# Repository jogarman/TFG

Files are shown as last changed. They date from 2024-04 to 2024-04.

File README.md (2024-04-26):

## Proyecto Fin de Grado de Ingeniería Mecánica
### Presentado en septiembre de 2016 en la Universidad de Salamanca



Echale un vistazo al ->
[Resumen.pdf](https://github.com/jogarman/TFG/files/15133371/Resumen.pdf)

Los videos, esquemas y código también son interesantes!!

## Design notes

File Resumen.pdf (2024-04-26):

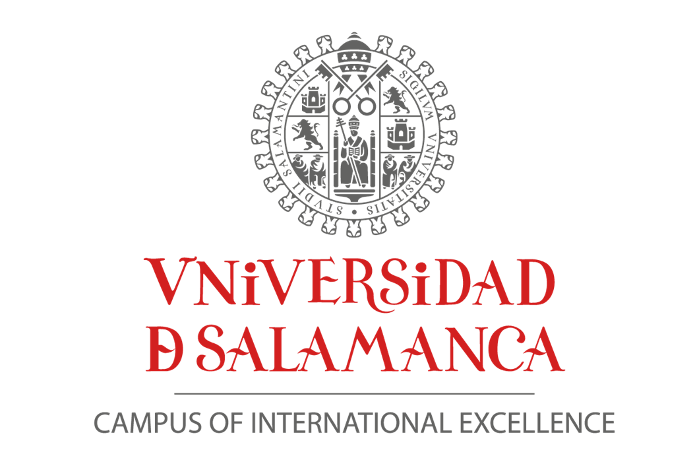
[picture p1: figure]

## DISEÑO Y REALIZACIÓN DE UN ROBOT BÍPEDO MICROCONTROLADO

GRADO EN INGENIERÍA MECÁNICA ESCUELA POLITÉCNICA SUPERIOR DE ZAMORA DEPARTAMENTO DE FÍSICA APLICADA ÁREA DE ELECTRÓNICA

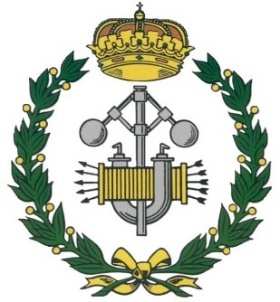
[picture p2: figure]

TFG-RESUMEN

AUTOR: JOSÉ GARCÍA MANZANARO

TUTOR: BEATRIZ GARCÍA VASALLO

COTUTOR: MIGUEL ÁNGEL RABANILLO DE LA FUENTE

FECHA DE ADJUDICACIÓN: MARZO DE 2016

FECHA DE PRESENTACIÓN: SEPTIEMBRE DE 2016

TFG-Resumen | José García Manzanaro
1 | P á g i n a

RESUMEN

El presente proyecto explica el funcionamiento y fabricación de un robot bípedo autónomo. Dicho robot es capaz de caminar frontalmente, girar a los lados y detectar obstáculos siempre asistido por un acelerómetro con giróscopo y un sensor de ultrasonidos.

Es un trabajo que ha sido multidisciplinar desde el primer momento. Combina varias técnicas: diseño mecánico, impresión 3D, electrónica y programación que unidas dan lugar a la mecatrónica orientada a la bipedestación.

Comienza con una introducción sobre el estado de la técnica en robótica y en la impresión 3D por deposición. En este punto, hay recalcar que se construyó una impresora 3D para la realización del robot.

A continuación, el trabajo se desglosa en 4 capítulos:

- Capítulo 1. Mecánica del robot
- Capítulo 2. Electrónica
- Capítulo 3. Programación y código
- Capítulo 4. Bipedestación y características finales.

CAPÍTULO 1. MECÁNICA DEL ROBOT

En esta sección se explica cómo fue diseñado y construido en orden cronológico

- Diseño global
- Diseño de los engranajes para las articulaciones
- Diversas uniones
- Ilustración con diseño final

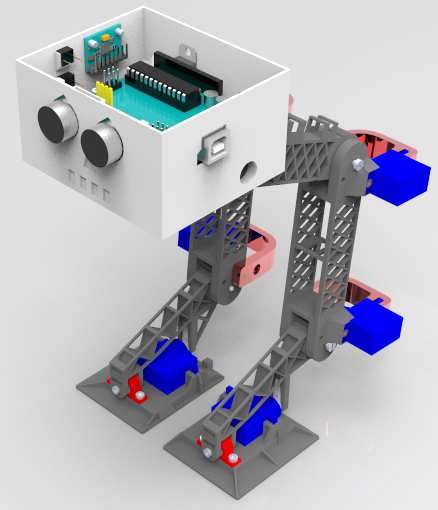
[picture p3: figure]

Ilustración 1. Diseño final

CAPÍTULO 2. ELECTRÓNICA

Se enumeran todos los componentes y se explica el funcionamiento de todos ellos, haciendo especial hincapié en el acelerómetro con giróscopo, también llamado IMU (Inertial Motion Unit) o MPU (Motion Process Unit). Entre estos dos términos existe una diferencia que se explica en la introducción de este punto. El esquema del apartado IMU es el siguiente:

- Protocolo I2C
- Tecnología MEMS (MicroElectroMechanical Systems)
- Funcionamiento del acelerómetro
- Funcionamiento del giróscopo
- Filtro complementario

CAPÍTULO 3. PROGRAMACIÓN Y CÓDIGO

En este capítulo se explica el funcionamiento de las rutinas principales haciendo referencia al código y organigramas de los anexos. También se describe el funcionamiento de la forma de caminar y cómo interactúa con el acelerómetrogiróscopo y cómo detecta obstáculos y gira, pero rutina a rutina.

Las rutinas explicadas son:

- IrA. Convierte el valor de la articulación al valor que recibe el servo.
- Posición de Inicio. Equilibra la cabeza colocándola en horizontal. Funciona sobre planos inclinados
- Ir Hasta. Se inclina lateralmente
- Zancada derecha/izquierda. Da una zancada
- Ir A Paso. Lleva al robot una posición (o a un paso) determinada, en un tiempo determinado y detecta si se cae
- Evitar desde derecha/izquierda. Detecta y evita obstáculos
- Programa Caminar1. Programa principal. Camina recto, detecta obstáculos y gira con ayuda del acelerómetro y giróscopo. Es lento
- Programa Caminar2. Programa secundario. Más primitivo. Solo camina, pero es más rápido

En los anexos pueden encontrarse el código y los organigramas de estas rutinas y algunos más.

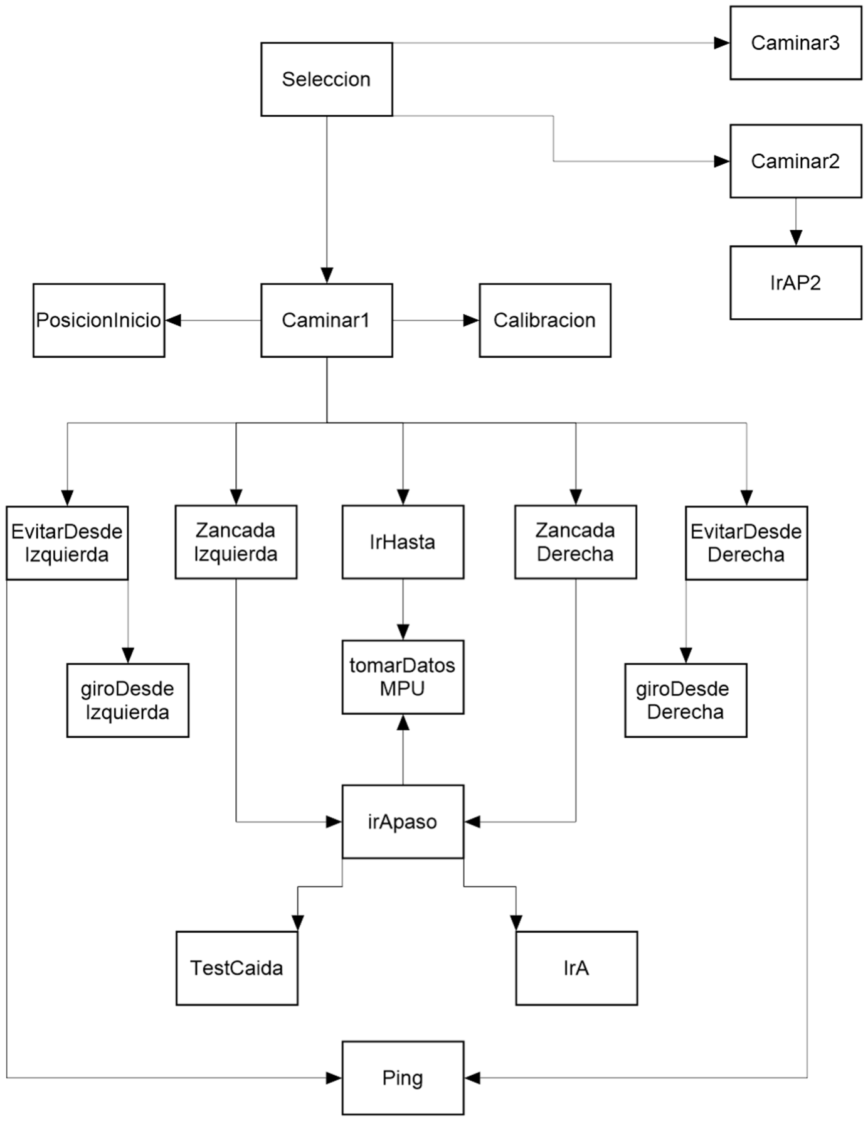
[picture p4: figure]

Ilustración 2. Organigrama del código

CAPÍTULO 4. BIPEDESTACIÓN Y CARACTERÍSTICAS FINALES

En la parte de la bipedestación se explica cómo funciona el robot:

El avance del robot es simple: se inclina, se levanta una pierna, se la hace avanzar, se asienta en una nueva posición y se inclina hacia la nueva posición. Al final de cada zancada utiliza el sensor de ultrasonidos para saber si hay algún obstáculo, y si lo hay, lo rodea en la dirección opuesta a la zancada (si es la zancada izquierda, lo rodea hacia la derecha, y viceversa).

Durante la elaboración de los códigos de movimiento se encontraron algunas reglas y particularidades a las que se hace referencia:

- Sumatorio de ángulos igual a 360

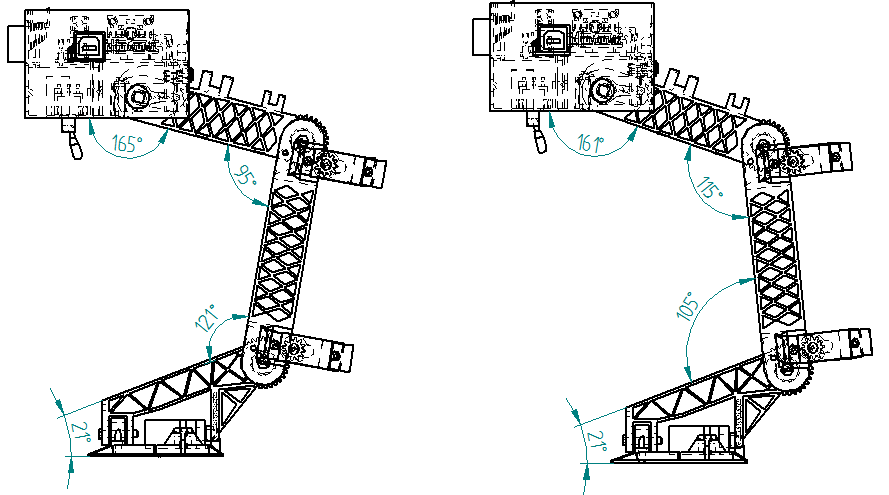
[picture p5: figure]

Para asentar el pie, se comprobó que los ángulos debían sumar lo mismo. En la teoría 360º

- Enlace entre zancadas

Se explica cómo se consiguió que caminara recto renunciando a caminar rápido. Consiste en cambian la distribución de pesos lateralmente y no en diagonal. Cuando se hace en diagonal el pie nunca se apoya completamente recto, principalmente por la baja precisión de los componentes.

- Caminar recto

Se profundiza en los problemas que tiene el robot para caminar recto y se concluye que la mejor forma para que así lo hiciera sería añadir un magnetómetro para conocer el norte terrestre y poder corregir el rumbo cuando sea necesario

En cuanto a características finales de algunos parámetros importante del proyecto:

- Desglose de coste
- Características técnicas finales
- Líneas de futuro

ANEXOS

En los anexos, aparte de encontrar el código completo explicado y con ordinogramas y demás tablas y datos relativos al proyecto, se encuentra la lista de piezas con los diseños en CAD impresos, y los componentes (también en CAD) modelizados para este proyecto.

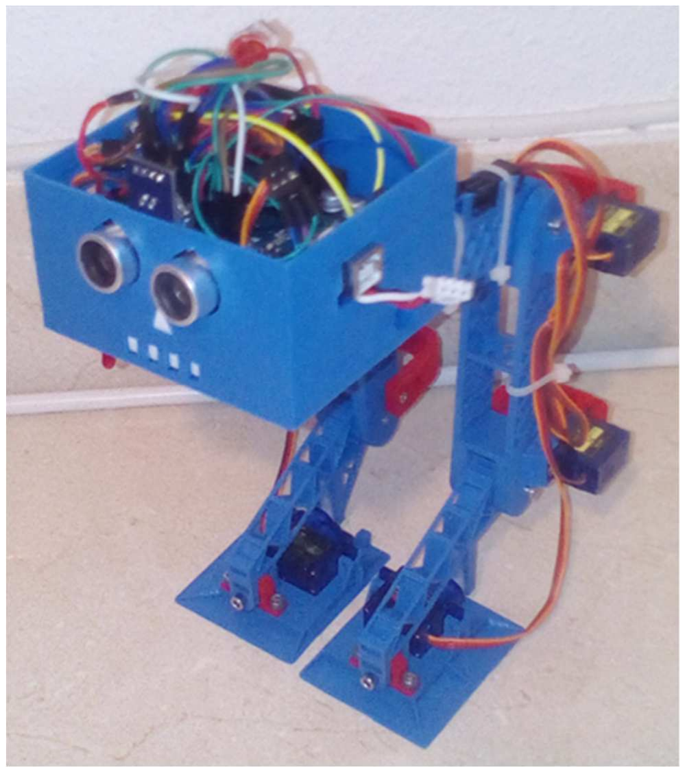
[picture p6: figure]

Ilustración 3. Fotografía final del robot

FUENTES DE INFORMACIÓN

- Esteban Viso El origen de la palabra robot. Enero 2016 http://m.xatakaciencia.com/robotica/el-origen-de-la-palabra-robot
- Real Academia Española
http://dle.rae.es/?id=WYRlhzm
- Escuela técnica Superior de Ingeniería de Sistemas Informáticos. Universidad Politécnica de Madrid https://www.etsisi.upm.es/museo_virtual/origenes/jmjacquard
- Comunicación en visita (2010) y Centro de Automática y Robótica (CAR) CSIC-UPM.
- Honda Motor Co.
http://world.honda.com/ASIMO/technology/2000/index.html
- Distribuidor Oficial de Nao
http://aliverobots.com/nao
- E. Ackerman and E. Guizzo Spectrum Boston Dynamics Now Belongs to Google IEEE 14 Dec 2013
http://spectrum.ieee.org/automaton/robotics/military-robots/bostondynamics-now-belongs-to-google
- E. Ackerman, ATLAS DRC Robot Is 75 Percent New, Completely Unplugged. Spectrum IEEE, 20 junio 2015: http://spectrum.ieee.org/automaton/robotics/military-robots/atlas-drcrobot-is-75-percent-new-completely-unplugged
- Página oficial de Boston Dynamics.
www.bostondynamics.com
- Página oficial del proyecto ICub http://www.icub.org/

- E. Guizzo Researchers Build Fast Running Robot Inspired by Velociraptor Spectrum IEEE. 29 May 2014 http://spectrum.ieee.org/automaton/robotics/robotics-hardware/fastrunning-biped-robot-based-on-velociraptor
- Comunicación en conferencia en la Escuela Politécnica Superior de Zamora. 2014
- Especificaciones de los plásticos. hxx, proovedor de sistemas de impresión 3D
http://hxx.es/2015/03/12/materiales-de-impresion-3d-i-pla-acidopolilactico/
http://hxx.es/2015/03/23/materiales-de-impresion-3d-ii-abs-acrilonitrilobutadieno-estireno/
- Página oficial de Arduino. https://www.arduino.cc/en/Reference/Comparison
- Página oficial de Fritzing http://fritzing.org/projects/mpu-6050-board-gy-521-acelerometro-ygiroscopio
- Página oficial del fabricante (Invensense) del MPU6050 https://www.invensense.com/products/motion-tracking/6-axis/mpu-6050/
- Página especializada en tutoriales de Arduino http://www.prometec.net/bus-i2c/
- Página de los laboratorios SANDIA http://www.sandia.gov/mstc/mems_info/movie_gallery.html
- National Informal STEM Education Network (NISE Network) http://www.nisenet.org/sites/default/files/catalog/uploads/spanish/12194/electricsqueeze_images_13nov13_sp.pdf
- Página oficial del fabricante PCB http://www.pcb.com/techsupport/tech_accel.aspx

- Hoja de especificaciones MPU-6050 https://www.invensense.com/products/motion-tracking/6-axis/mpu-6050/
- Instrumentation-Electronics http://www.instrumentationtoday.com/?s=accelerometer
- Á. Solera Ramírez. El filtro de Kalman. Banco central de costa rica división económica departamento de investigaciones económicas. 2003

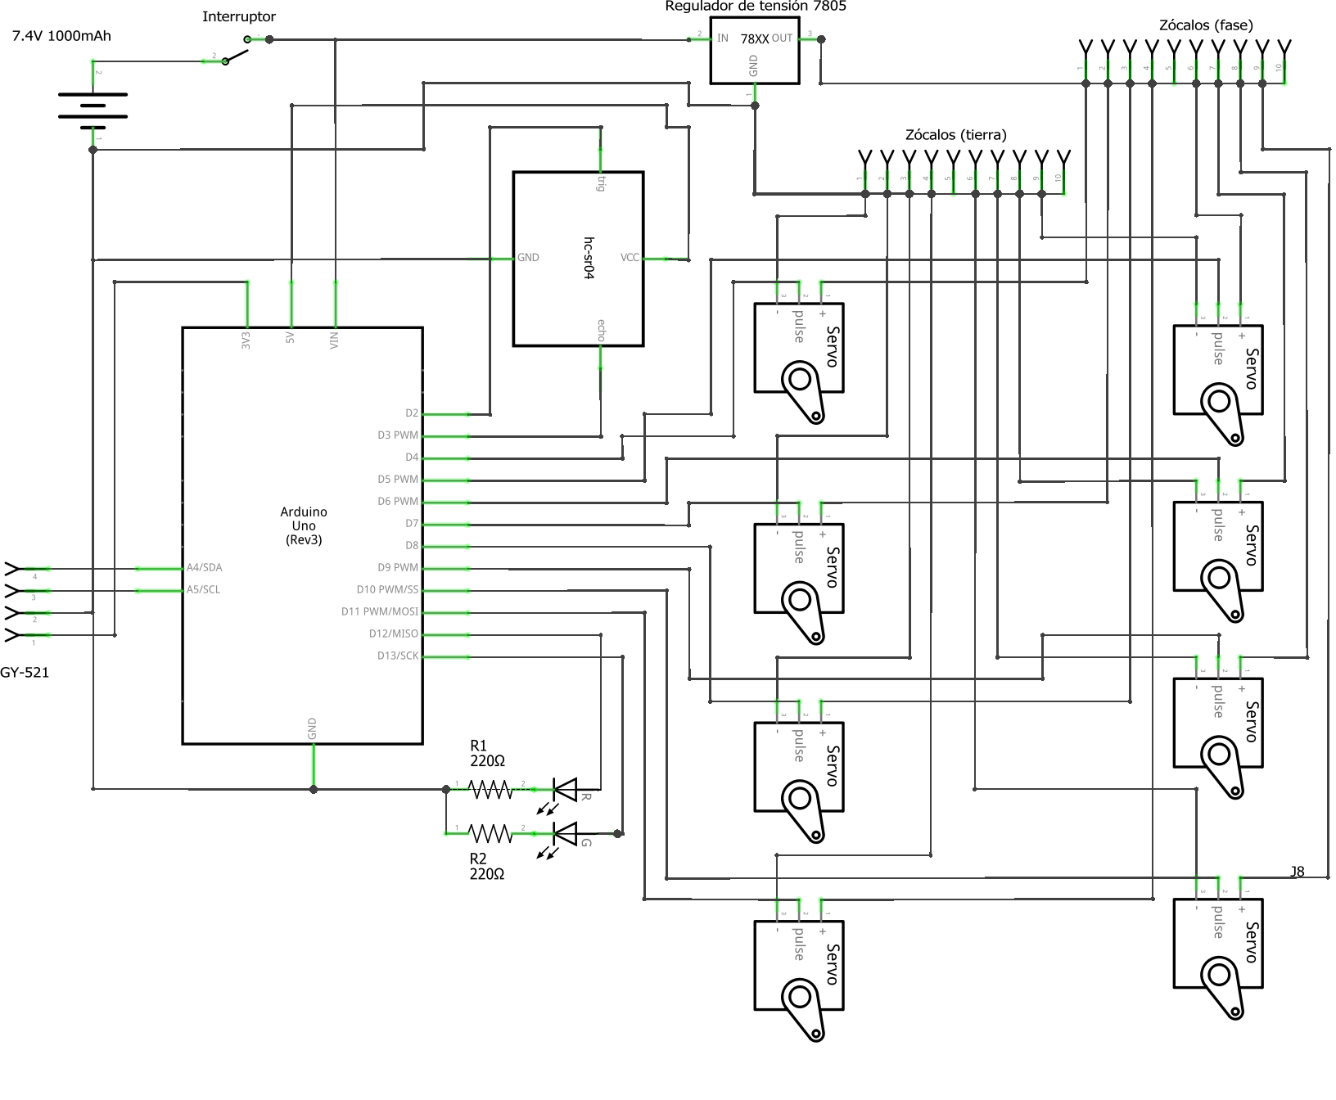
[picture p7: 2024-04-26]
Planos eléctricos/Plano electrico global.png

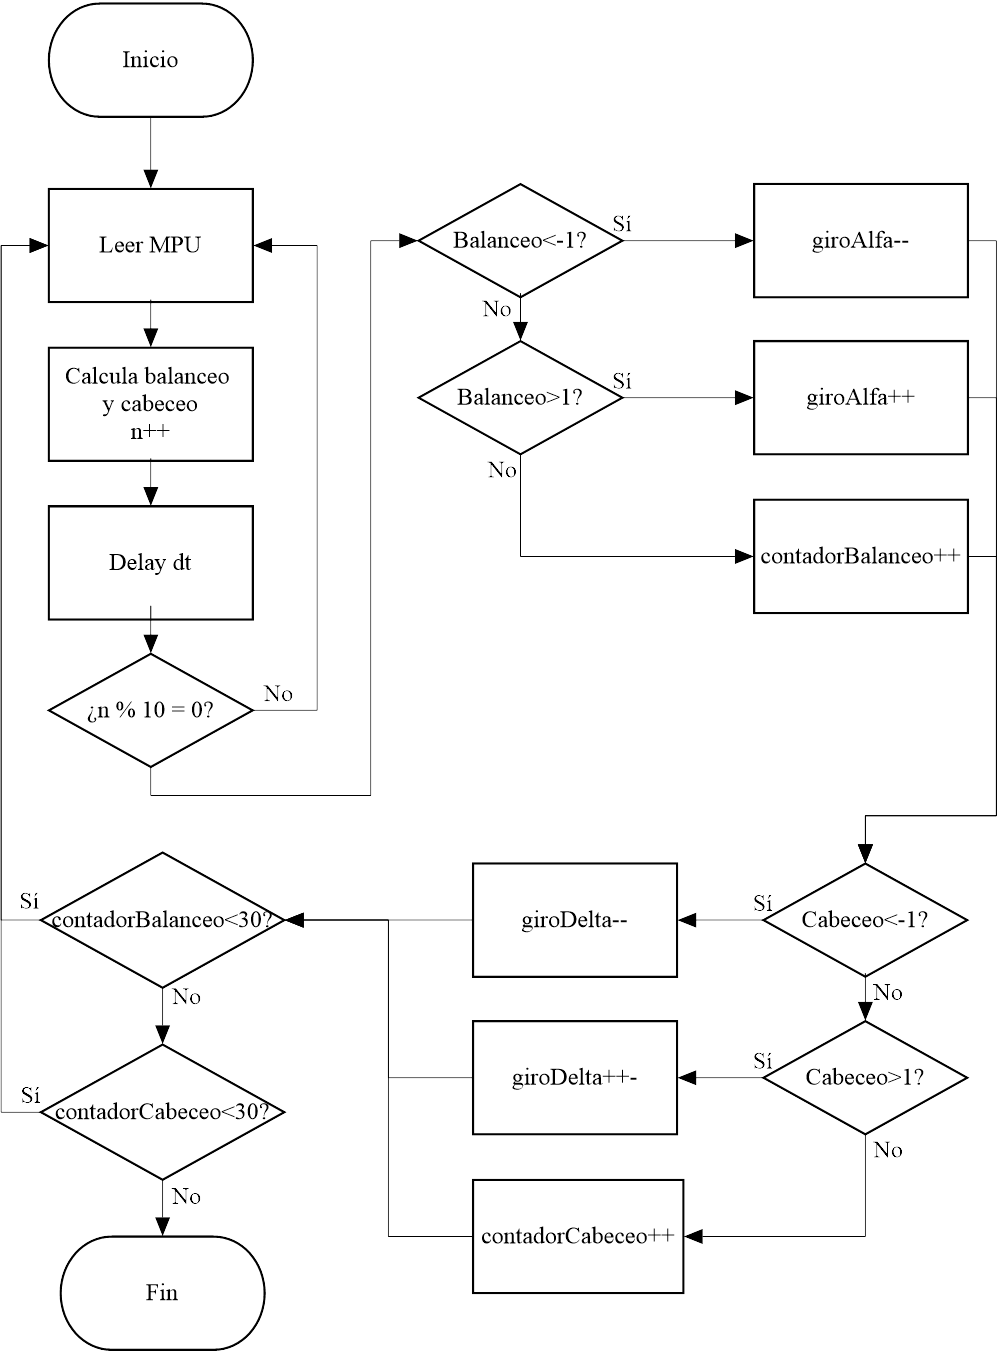
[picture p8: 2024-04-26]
Organigramas/posicionInicio.png

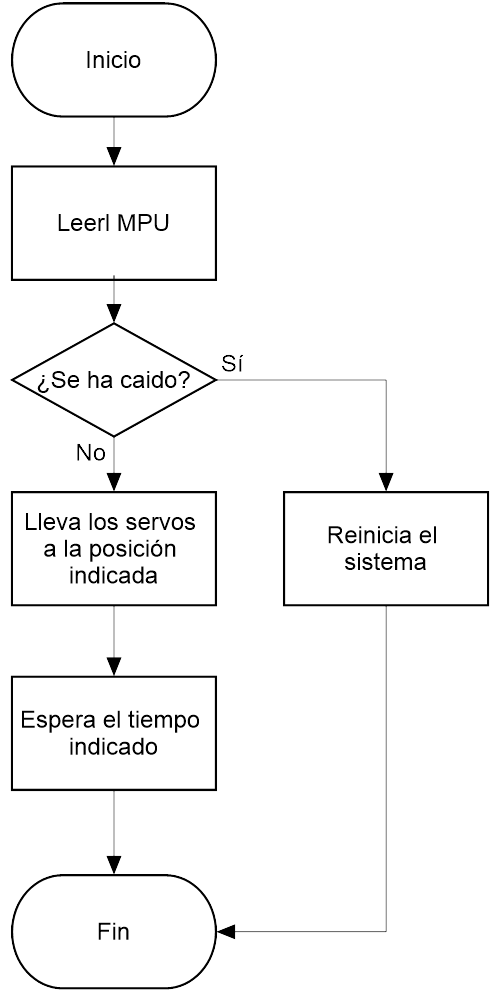
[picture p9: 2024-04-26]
Organigramas/IrAPaso.png

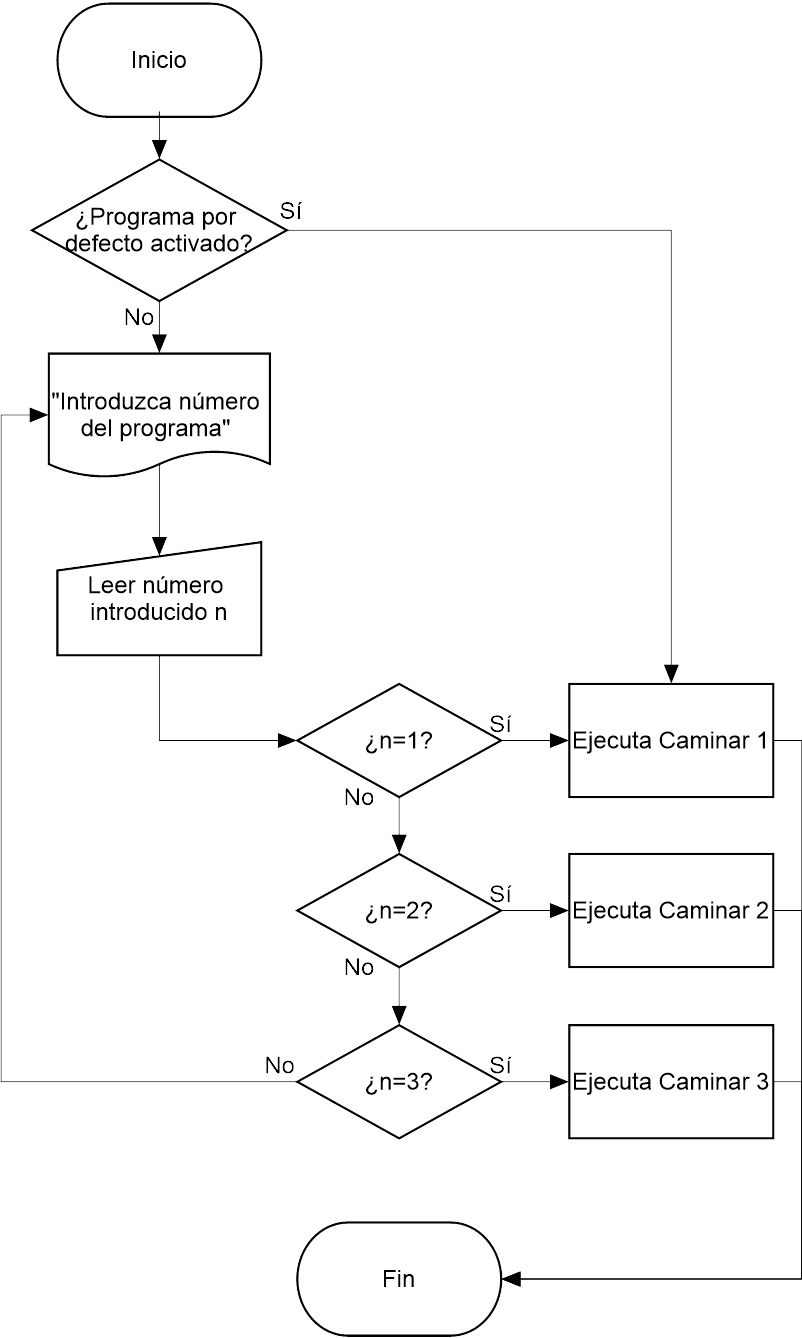
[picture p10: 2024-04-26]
Organigramas/Selector.png

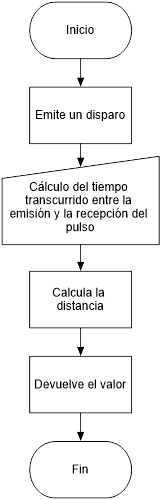
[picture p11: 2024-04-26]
Organigramas/ultrasonidos.png

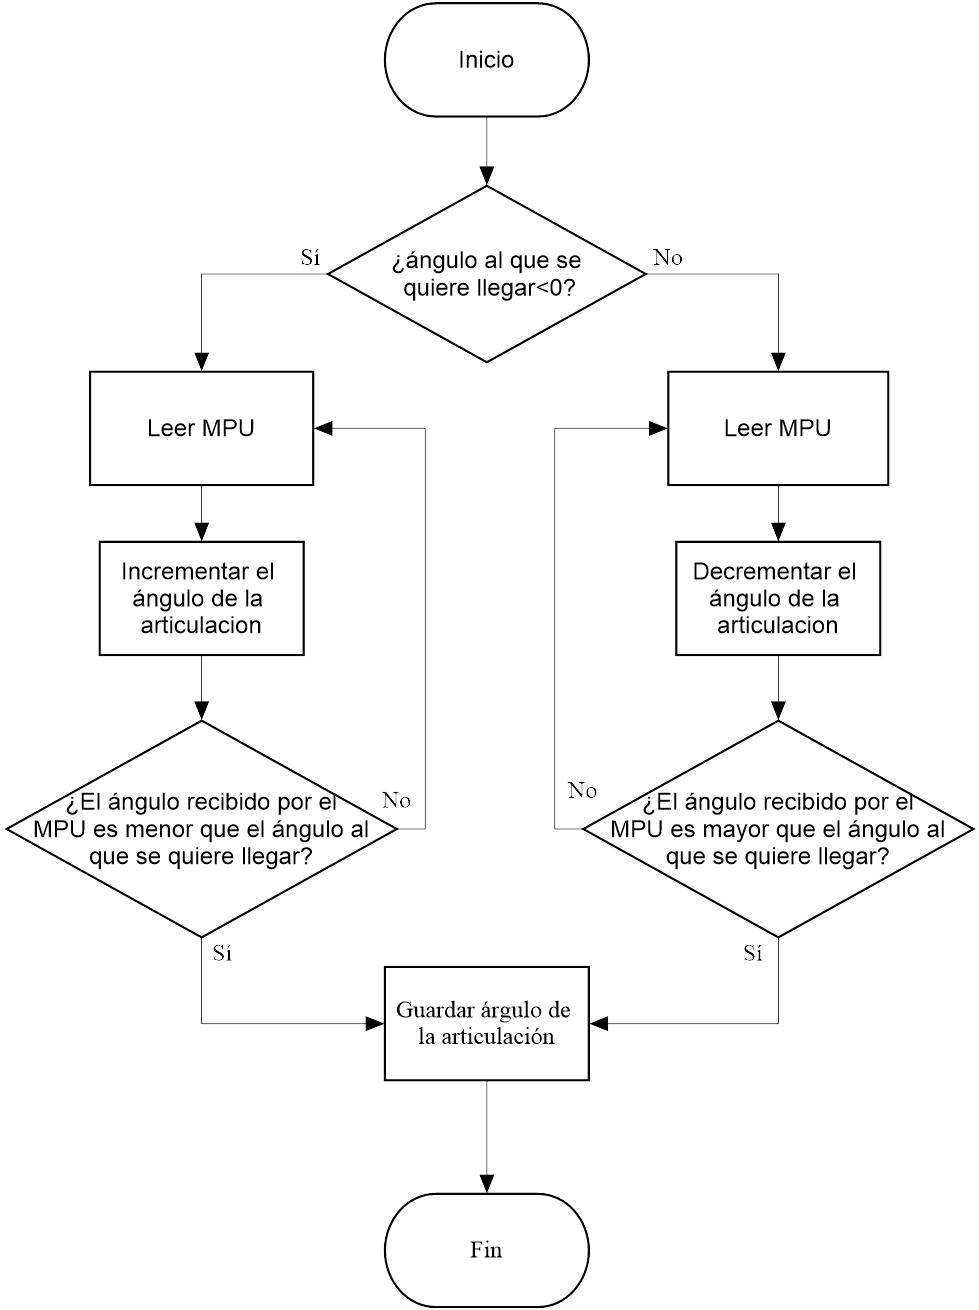
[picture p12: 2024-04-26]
Organigramas/irHasta V2.png

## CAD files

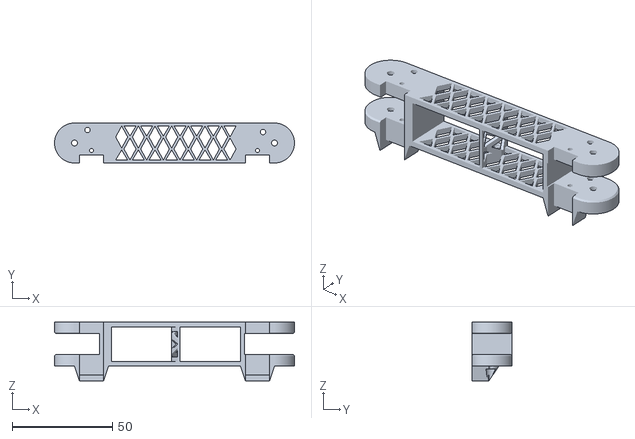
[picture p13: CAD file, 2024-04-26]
Archivos para imprimir 3D .stl/1.05 ESPINILLA n.stl
120.0 x 20.0 x 29.4

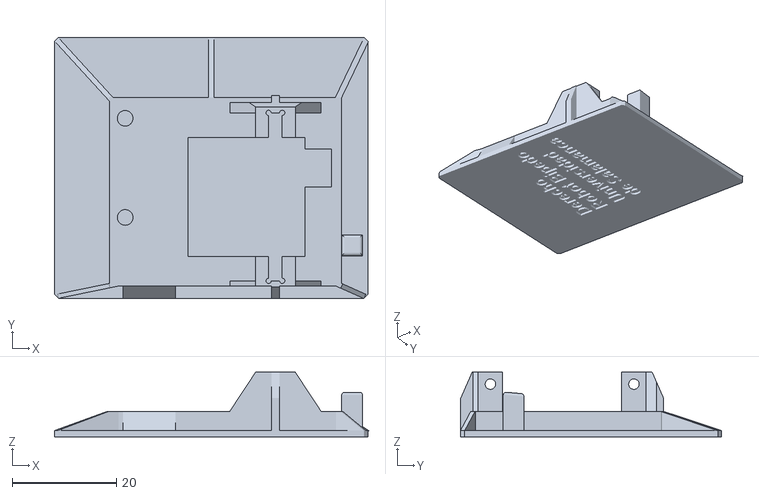
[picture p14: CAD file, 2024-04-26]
Archivos para imprimir 3D .stl/1.01b PIE.stl
60.2 x 50.1 x 12.4

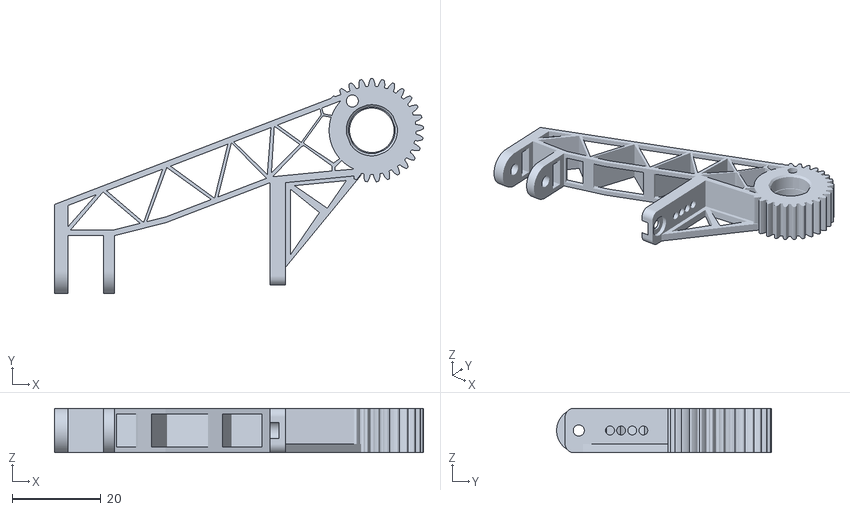
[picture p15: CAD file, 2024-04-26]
Archivos para imprimir 3D .stl/1.04 EMPEINE.stl
83.0 x 48.3 x 10.0

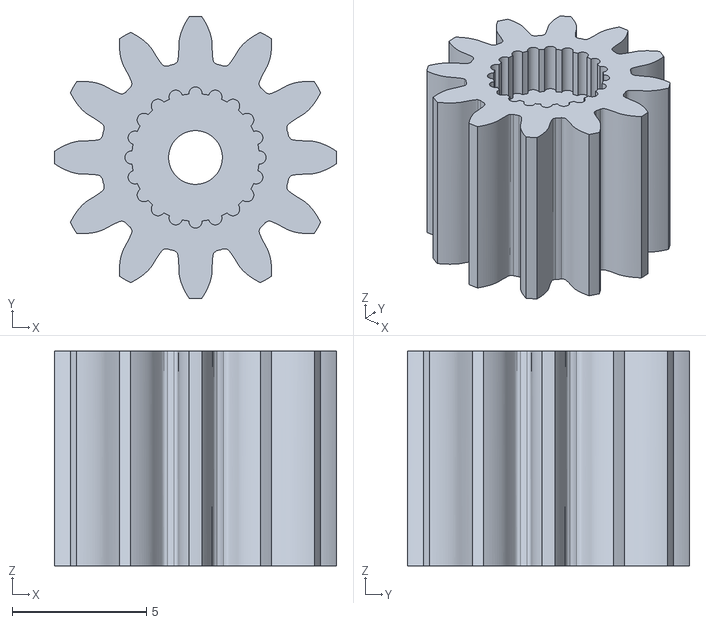
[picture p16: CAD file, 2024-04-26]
Archivos para imprimir 3D .stl/1.03 PIÑON.stl
10.5 x 10.5 x 8.00

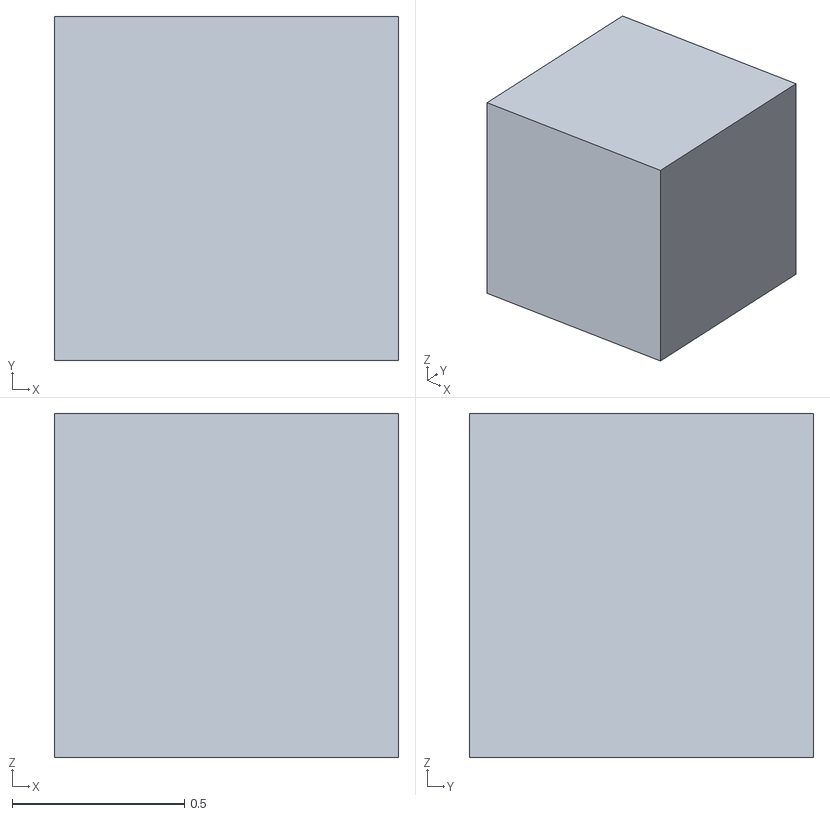
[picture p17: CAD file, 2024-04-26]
Archivos para imprimir 3D .stl/cubo 1x1x1 para extruir piñones.stl
1.00 x 1.00 x 1.00

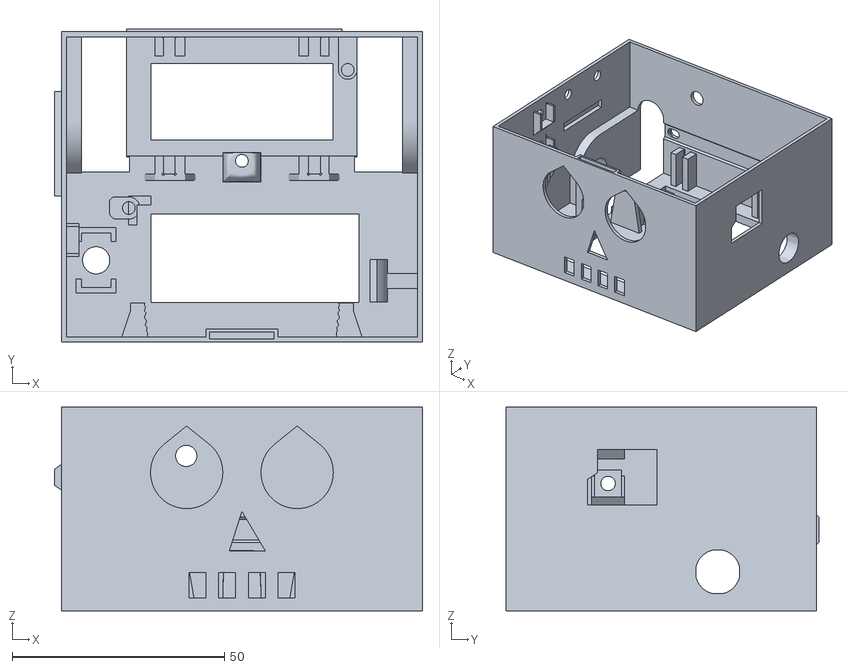
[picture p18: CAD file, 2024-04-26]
Archivos para imprimir 3D .stl/1.07 CAJA CABEZA.stl
86.6 x 73.6 x 48.0

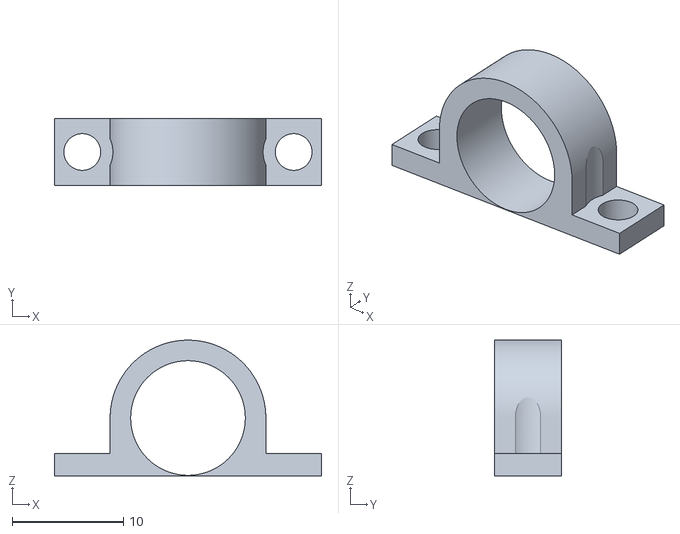
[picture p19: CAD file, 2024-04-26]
Archivos para imprimir 3D .stl/1.02 SOPORTE PIE.stl
24.0 x 6.00 x 12.2

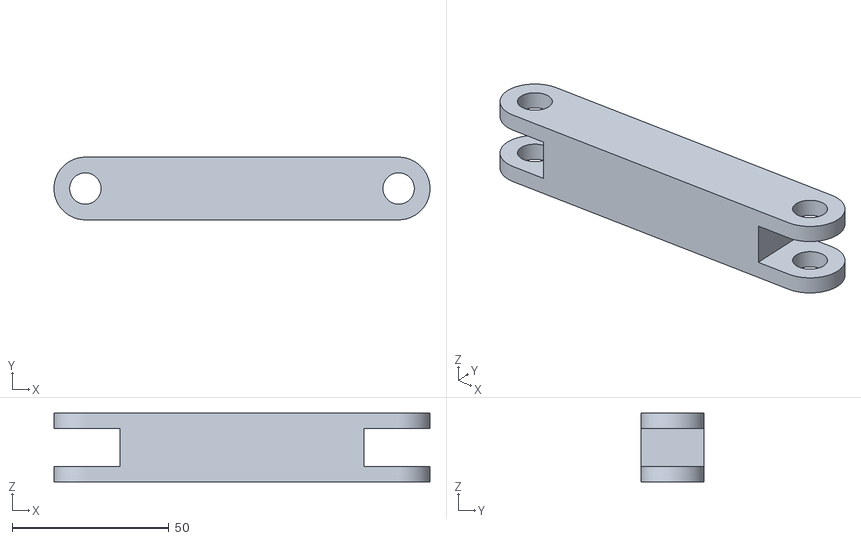
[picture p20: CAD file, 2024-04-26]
Archivos para imprimir 3D .stl/1.05 espinilla.stl
120.0 x 20.0 x 22.0

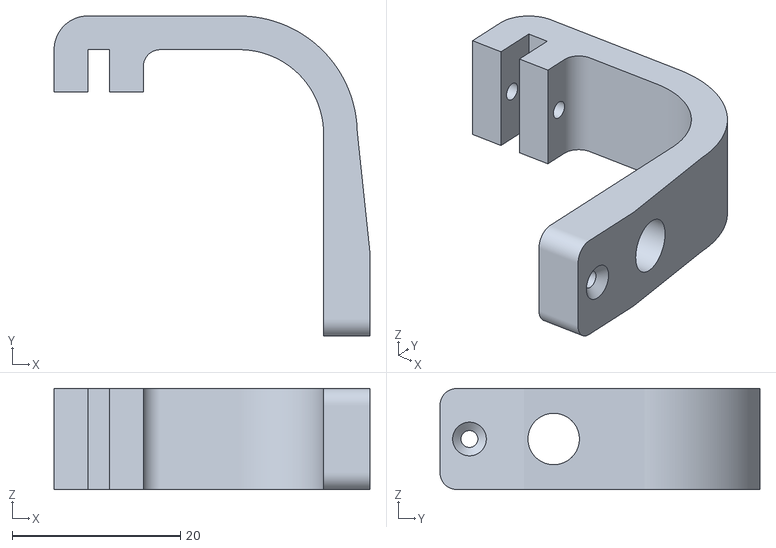
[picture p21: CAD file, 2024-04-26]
Archivos para imprimir 3D .stl/1.08 APOYOS SERVOS.stl
37.5 x 38.0 x 12.0

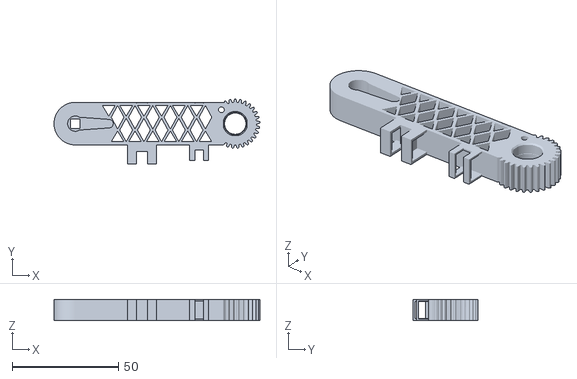
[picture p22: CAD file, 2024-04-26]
Archivos para imprimir 3D .stl/1.06 FEMUR.stl
96.7 x 30.6 x 10.0

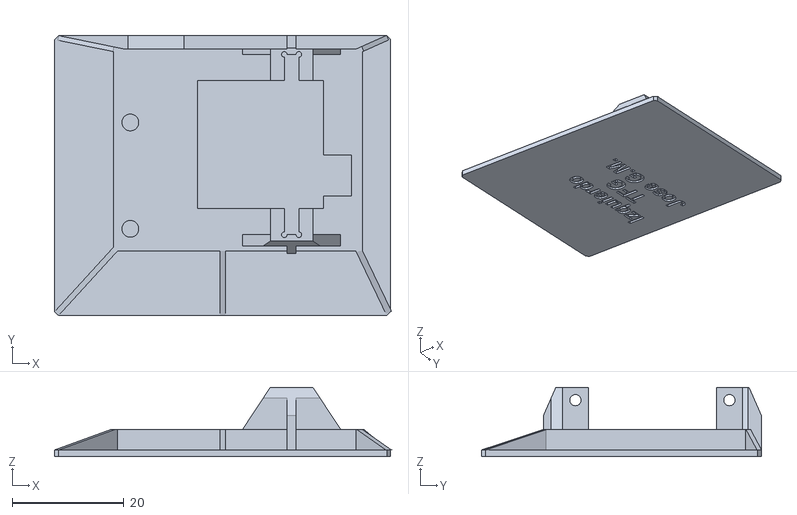
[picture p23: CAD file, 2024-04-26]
Archivos para imprimir 3D .stl/1.01a PIE.stl
60.2 x 50.1 x 12.4

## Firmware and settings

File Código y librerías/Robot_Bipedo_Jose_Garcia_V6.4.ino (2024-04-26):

/*
   RoboJop-----------------------------------------------------------------------------Septiembre de 2016
 ********************************************************************************************************
   Autor: Jose Garcia Manzanaro
   Tutora: Beatriz Garcia Vasallo
   Proyecto: Robot Bipedo Microcontrolado
   Trabajo Fin de Grado
   Universidad de Salamanca
   Contacto: josegm@usal.es

   English
   The code below is able to control autonomously a biped robot with 8 degrees of freedoom, specialy
   desing to be generated by 3D printing. This code control the movement step by step by a giroscope
   MPU5060 and can avoid obstacles with an ultrasonic sensor HC-SR04.

   Español
   El siguiente código es capaz de controlar de forma autónoma un robot bípedo de 8 grados de libertad
   diseñado para ser generado por una impresora 3D. Este código controla el movimiento posición a posición
   con ayuda de un giróscopo MPU5060 y evita obstaculos con ayuda de un sensor de ultrasonidos HC-SR04.
   ******************************************************************************************************
*/

//*******************************************************************************************************
// Comienzo de la definicion de variables y constantes **************************************************
//*******************************************************************************************************


//////////////////////////////////////////////////////
// Definicion de includes
//////////////////////////////////////////////////////

#include <Wire.h>
#include <MPU6050.h>
#include <Servo.h>

//////////////////////////////////////////////////////
// Declaracion de constantes para el MPU
//////////////////////////////////////////////////////
const float pi = 3.1415926535897932384626433832795;
const float GraRad = 180 / pi;

//El acelerometro devuelve los valores que registra en un rango de numeros entre -16384 y +16384. Para
//conocer la aceleración exacta hay que divir el valor devuelto por el acelerómetro entre la sensibilidad 
//establecida en 2g.
//La siguinete cosnstante se utiliza para obtener los valores de la aceleración y obtener la inclinación
//con resultado en radianes.
const float AaR = 16384.00; //de Acelerometro A Radianes

//El giroscopo devuelve los valores registrados en el mismo rango que el acelerometro. La sensibilidad
//esta establecida en +-250º/s.
//Para determinar la velocidad angular se multiplica el valor registrado por la siguiente constante:
//+-250º/s= 32768/250= 131.072 datos*s/º
const float GaG = 131.072; //de Giroscopo A Grados

//////////////////////////////////////////////////////
// Declaracion de variables del MPU//////////////////
//////////////////////////////////////////////////////
MPU6050 mpu; // Definicion de la estructura de datos tipo MPU6050

int16_t ax, ay, az;//int16 define un integer con signo
int16_t gx, gy, gz;
float balanceoA, cabeceoA, balanceoG, cabeceoG, guinadaG, balanceo, cabeceo, guinada;
float ganancia = 0.9; //expresa el nivel de aceptacion entre el giroscopo y el acelerometro

//Valores que ajustan la inclinacion del MPU para que se corresponda con la cabeza
float calibracionCabeceo = -1, calibracionBalanceo = 2.8;

int tiempoChequeo = 250; //en milisegundos. Tiempo para el que se considera estable la señal del MPU
int dt = 5; //intervalo de tiempo por chequeo en milisegundos

//------------------------------Declaracion de variables del Ultrasonidos--------------------------------
const int pinEco = 3;
const int pinDisparo = 2;
const int distanciaSeguridad = 15; //distancia en cm a la que se detecta el obstaculo

//------------------------------Declaracion de variables de los LEDs ------------------------------------
const int pinRojo13 = 13;
const int pinVerde12 = 12;

//-------------------------------------------------------------------------------------------------------
// Relacion entre las definiciones de xxx0 y la rotula correspondiente
//-------------------------------------------------------------------------------------------------------
/*
  Las referencias relativas a los numeros se corresponden con articulaciones de la siguiente forma:
  xxx0 =>> pie izquierdo
  xxx1 =>> pie derecho
  xxx2 =>> rotula del tobillo izquierdo
  xxx3 =>> rotula del tobillo derecho
  xxx4 =>> rotula de la rodilla izquierda
  xxx5 =>> rotula de la rodilla derecha
  xxx6 =>> rotula de la cabeza izquierda
  xxx7 =>> rotula de la cabeza derecha

  Los angulos de las articulaciones tambien se denominan de la siguiente forma:
  Alfas son las articulaciones de los pies, Betas los tobillos, Gamma las rodillas
  y Delta los de la cabeza los enumerados como 1 son las articulaciones de la
  parte izquierda y los enumerados como 2 son las articulaciones de la derecha.
  P.Ej beta2 -> tobillo derecho
*/

//-----------------------------------
// TODOS LOS ANGULOS SON EN GRADOS
//-----------------------------------

//-----------------------------Declaracion de pines de los servos----------------------------------------
const int pinSer0 = 9;  //Pin del servo 0 (pie izq)
const int pinSer1 = 6;  //Pin del servo 1
const int pinSer2 = 8;  //Pin del servo 2
const int pinSer3 = 7;  //Pin del servo 3
const int pinSer4 = 10; //Pin del servo 4
const int pinSer5 = 5;  //Pin del servo 5
const int pinSer6 = 11; //Pin del servo 6
const int pinSer7 = 4;  //Pin del servo 7

//------------------------------Declaracion de los servos -----------------------------------------------
Servo ser0; // pie izq
Servo ser1; // pie der
Servo ser2; // r1 izq. r1 es la rotula del tobillo
Servo ser3; // r1 der
Servo ser4; // r2 izq. r2 es la rotula de la rodilla
Servo ser5; // r2 der
Servo ser6; // r3 izq. r3 es la rotula de la cabeza
Servo ser7; // r3 der

//----------------------------- Angulos entre las articulaciones ----------------------------------------
int ang0; // ang= angulo de la articulacion
int ang1;
int ang2;
int ang3;
int ang4;
int ang5;
int ang6;
int ang7;

//------------------------------
// Ajustes iniciales
//------------------------------
/*
  Calibramos el robot cada vez que lo montamos modificando el valor de ValIni.
  angIni es el angulo que tiene la articulacion para la posicion inicial.
  Por ejemplo, con ayuda de un transportador se coloca la articulación en el angulo angIni y se
  cambia el valor de valIni para que este valor del servo coincida con el valor de la articulacion.
*/
//----------------------------- Valores iniciales de los servos ----------------------------------------
//Valores para la posicion estatica. Son valores caracteristicos del montaje
int  valIni0 = 110;  // Pie izquierdo. Aumentar es a la derecha
int  valIni1 = 112; // Pie derecho. Aumentar es a la derecha
int  valIni2 = 90; // R1 izq  Aumentar el valor es abrir la articulacion
int  valIni3 = 77;  // R1 der  Aumentar el valor cerrar la articulacion
int  valIni4 = 72;  // R2 izq  Aumentar el valor es cerrar la articulacion
int  valIni5 = 121; // R2 der  Aumentar el valor es abrir la articulacion
int  valIni6 = 71;  // R3 izq  Aumentar el valor es abrir la articulacion
int  valIni7 = 131; // R3 der  Aumentar el valor es cerrar la articulacion

//----------------------------- Valores propios de las articulaciones -----------------------------------
/*
  Fijamos el angulo que queramos que tengan las articulaciones para la posicion de equilibro,
  esto es independientemente de como hallamos montado el robot
*/
int angIni0 = 90;
int angIni1 = 90;
int angIni2 = 121;
int angIni3 = 121;
int angIni4 = 114;
int angIni5 = 114;
int angIni6 = 175;
int angIni7 = 175;

//Se establece el sentido de giro para que abra o cierre como debe.
int sentido0 = +1;
int sentido1 = +1;
int sentido2 = +1;
int sentido3 = -1;
int sentido4 = -1;
int sentido5 = +1;
int sentido6 = +1;
int sentido7 = -1;

//valor de la reduccion para cada articulacion dada
float redu0 = 1.0;
float redu1 = 1.0;
float redu2 = 2.4;
float redu3 = 2.4;
float redu4 = 2.4;
float redu5 = 2.4;
float redu6 = 1.0;
float redu7 = 1.0;

//----------------------------- Variables globales de datos del giroscopo -------------------------------
int inicioA1; //giroscopoAlfa para la posicion de inicio. Pie. Referencia del giroscopo
int inicioA2;
int inicioD1; //giroscopoDelta para la posicion de inicio. Cabeza
int inicioD2;

//referencia para los pies tomada cuando se termina de inclinar hacia un lado con irHasta()
int incliA1;
int incliA2;

//----------------------------- Variables para el control de velocidad de ejecucion ---------------------
int velDef  = 200; //velocidad por defecto del programa principal (Caminar1)
int velDef2 = 200; //velocidad pro defecto del programa 2 (Caminar2)

//-------------------------------- Funcion para reiniciar el sistema ------------------------------------
void(* reset) (void) = 0; //resetea. Regresa a la posición 0 de memoria

//--------------------------------Variables del selector de ejecucion-----------------------------------
//Selecciona la forma de caminar
char estado = 0;
boolean preguntarCaminarPorDefecto = 1; //1 --> por defecto en Caminar 1. 0 --> espera a recibir el
                                        //numero del Caminar a ejecutar

//*******************************************************************************************************
// Fin de la definicion de variables y constantes. ******************************************************
//*******************************************************************************************************



//*******************************************************************************************************
// Comienzo del establecimiento de definiciones e inicializaciones para la ejecucion ********************
//*******************************************************************************************************

void setup() {
  //-------------------------- Deficinion de pines de los LEDs -----------------------------------------
  pinMode(pinRojo13, OUTPUT);
  pinMode(pinVerde12, OUTPUT);
  //pinMode(pinAzul3, OUTPUT);

  // ------------------ Definicion de pines del SENSOR DE ULTRASONIDOS HC-SR04 -------------------------
  pinMode(pinDisparo, OUTPUT);
  pinMode(pinEco, INPUT);

  //-------------------------------Iniciar canal de comunicacion ---------------------------------------
  Serial.begin(9600); //para detectar fallos en el programa y la seleccion de ejecucion
  Serial.println("Conectado");

  // ------------------------------Inicializacion del giroscopo----------------------------------------
  mpu.initialize();
  // Solo para depuracion
  //Serial.println(mpu.testConnection() ? "Connected" : "Connection failed");

  //----------------------------- Asignacion de pines de los servos ------------------------------------
  ser0.attach(pinSer0);  //Cable negro
  ser1.attach(pinSer1);  //Cable amarillo
  ser2.attach(pinSer2);  //Cable verde
  ser3.attach(pinSer3);  //Cable rojo
  ser4.attach(pinSer4);  //Cable verde
  ser5.attach(pinSer5);  //Cable verde
  ser6.attach(pinSer6);  //Cable verde
  ser7.attach(pinSer7);  //Cable rojo
}
//*******************************************************************************************************
// Fin del establecimiento de definiciones e inicializaciones para la ejecucion. ************************
//*******************************************************************************************************

//*******************************************************************************************************
//*******************************************************************************************************
// Comienzo de la ejecucion *****************************************************************************
//*******************************************************************************************************
//*******************************************************************************************************
void loop() {
  //------------------------------ Seleccion de Caminar -------------------------------
  if (preguntarCaminarPorDefecto == 1) {//para entrar por defecto al caminar1 si se activa el boolean
    Caminar1();
  }
  Serial.println("Introduzca el numero del programa que desea ejecutar");
  do {
    estado = Serial.read();  // El bucle permanece hasta que le llega uno de los caracteres 1, 2 o 3.
  } while  (estado != '1' and estado != '2' and estado != '3'); //cuando estado no es igual a 1, 2 ni 3
  //repite

  //pasa al programa de caminar elegido
  if (estado == '1') {
    Caminar1();
  }
  else if (estado == '2') {
    Caminar2();
  }
  else if (estado == '3') {
    Caminar3();
  }
}
//*******************************************************************************************************
// Fin de la ejecucion (loop) ***************************************************************************
//*******************************************************************************************************

///////////////////////////////////////////////////////////////////////
// Camina con giroscopo y evita obstaculos *************************///
///////////////////////////////////////////////////////////////////////
void Caminar1() {
  Calibracion(); //va a la posicion de inicio.
  delay (500);// este valor se aumenta cuando se quieren calibrar los servos
  posicionInicio(90, 90, 121, 121, 114, 114, 175, 175, 2000);//la posicion de prueba
  //Bucle infinito: se inclina, da una zancada a la derecha, se inclina, zancada a la
  //izquierda, se inclina, y así, sucesivamente
  //Al final de cada zancada chequea si hay algún obstaculo y lo rodea
  while (true) {
    irHasta(-8);      //- es inclinar a la izquierda y + es inclinar a la derecha
    zancadaDerecha();
    evitarDesdeDerecha();
    irHasta(8);
    zancadaIzquierda();
    evitarDesdeIzquierda();
  }
}

///////////////////////////////////////////////////////////////////////
// Camina rápido para demostracion *********************************///
///////////////////////////////////////////////////////////////////////
void Caminar2() {
  Calibracion(); //va a la posicion de inicio
  delay(1000);

  //da media zancada hasta situarse en una posición que pueda enlazar con la siguiente
  while (true) {
    IrAP2( 90,  90, 121, 121, 114, 114, 175, 175, velDef2);
    IrAP2( 93,  93, 121, 121, 114, 114, 175, 175, velDef2);
    IrAP2( 96,  96, 121, 121, 114, 114, 175, 175, velDef2);
    IrAP2( 99,  99, 121, 121, 114, 114, 175, 175, velDef2);
    IrAP2(101, 101, 121, 121, 114, 114, 175, 175, velDef2);
    IrAP2(103, 103, 121, 121, 114, 114, 175, 175, velDef2);
  }

  IrAP2(103, 102, 121, 118, 114, 110, 175, 175, velDef2);
  IrAP2(103, 101, 121, 115, 114, 106, 175, 175, velDef2);
  IrAP2(103, 100, 121, 118, 114, 102, 175, 175, velDef2);
  IrAP2(100,  99, 118, 124, 114,  98, 185, 173, velDef2);
  IrAP2( 99,  99, 116, 126, 114, 102, 187, 171, velDef2);
  IrAP2( 99,  99, 114, 128, 114, 102, 180, 172, velDef2);
  IrAP2( 99,  99, 112, 130, 114, 102, 175, 174, velDef2);
  IrAP2( 97,  96, 112, 130, 114, 102, 175, 175, velDef2);
  IrAP2( 95,  93, 112, 130, 114, 103, 175, 175, velDef2);
  IrAP2( 80,  80, 112, 130, 114, 104, 175, 175, velDef2);
  IrAP2( 80,  78, 116, 126, 116, 108, 173, 178, velDef2);
  IrAP2( 80,  78, 116, 126, 110, 108, 173, 178, velDef2);
  IrAP2( 80,  78, 116, 126, 105, 108, 173, 178, velDef2);
  IrAP2( 80,  78, 125, 126,  92, 108, 170, 180, velDef2);
  IrAP2( 80,  78, 125, 126,  91, 108, 168, 180, velDef2);
  IrAP2( 80,  78, 125, 126,  90, 108, 167, 180, velDef2);
  IrAP2( 80,  78, 130, 126,  89, 108, 164, 180, velDef2);
  IrAP2( 80,  78, 135, 126,  88, 108, 160, 180, velDef2);
  IrAP2( 81,  79, 140, 125,  87, 108, 160, 180, velDef2);
  IrAP2( 82,  81, 140, 123,  88, 108, 160, 180, velDef2);
  IrAP2( 82,  82, 140, 122,  89, 108, 160, 180, velDef2);
  IrAP2( 82,  82, 140, 121,  91, 108, 160, 178, velDef2);
  IrAP2( 85,  85, 140, 118,  91, 108, 165, 175, velDef2);
  IrAP2( 88,  88, 140, 115,  91, 108, 170, 172, velDef2);
  IrAP2( 90,  90, 139, 113,  94, 111, 175, 169, velDef2);
  IrAP2( 90,  90, 137, 111,  97, 115, 175, 169, velDef2);
  IrAP2( 90,  90, 135, 108, 100, 118, 175, 169, velDef2);
  IrAP2( 90,  90, 132, 105, 105, 121, 175, 169, velDef2);
  IrAP2( 92,  92, 130, 105, 108, 125, 175, 172, velDef2);
  IrAP2( 94,  94, 127, 105, 110, 127, 175, 174, velDef2);
  IrAP2( 97,  97, 120, 105, 112, 129, 175, 174, velDef2);
  IrAP2(100, 100, 120, 115, 115, 125, 175, 175, velDef2);
  IrAP2(103, 103, 121, 121, 115, 120, 175, 175, velDef2);
  IrAP2(103, 103, 121, 121, 114, 114, 175, 175, velDef2);
}

//--------------- programa vacante ------------------------
void Caminar3() {
  arcoIris();
}

//////////////////////////////////////////////////////
// Fuciones auxiliares **************************** //
//////////////////////////////////////////////////////
//---------------------Ayuda a calibrar el robot--------------------
void Calibracion() {
  ser0.write(valIni0);
  ser1.write(valIni1);
  ser2.write(valIni2);
  ser3.write(valIni3);
  ser4.write(valIni4);
  ser5.write(valIni5);
  ser6.write(valIni6);
  ser7.write(valIni7);
}

//-----------------------------Posicion de inicio con datos proporcionados por el giroscopo--------------
//----------El siguiente código posiciona la cabeza y los pies paralelos al suelo------------------------
void posicionInicio(int ang0, int ang1, int ang2,
                    int ang3, int ang4, int ang5,
                    int ang6, int ang7, int tiempoInicio) {

  boolean i;
  int contadorParaPasarBalanceo = 0;
  int contadorParaPasarCabeceo = 0;
  byte necesariosParaPasar = 30; //con 30 va bien, con 50 muy bien, pero tarda demasiado
  byte margenError = 1;          //+- grados de margen de error en la colocacion
  float giroAlfa1 = ang0 - balanceo,
        giroAlfa2 = ang1 - balanceo,
        giroDelta1 = ang6,
        giroDelta2 = ang7;

  ///////////////////////////////////////////////////////////////////////////////////////////////////////
  //do while, inicia un contador de balanceo y otro de cabeceo. El siguiente codigo hace que se necesiten
  //tres condiciones para pasar:
  //       -que pasen 2  segundos
  //       -que se halla llegado a la posicion de equilibro en balanceo (+-1º) 30 veces
  //       -que se halla llegado a la posicion de equilibro en cabeceo (+-1º)  30 veces
  ///////////////////////////////////////////////////////////////////////////////////////////////////////

  do {
    //tiempoInicio=2000ms/dt=5ms hace un minimo de 400 calculos.
    for (int n = 0; n < tiempoInicio / dt; n++) {
      mpu.getMotion6(&ax, &ay, &az, &gx, &gy, &gz);
      //Balanceo y cabeceo obtenidos de la aceleracion
      balanceoA = atan((az / AaR) / sqrt(pow((ay / AaR), 2) + pow((ax / AaR), 2))) * GraRad 
        + calibracionBalanceo;
      cabeceoA  = atan((ay / AaR) / sqrt(pow((ax / AaR), 2) + pow((az / AaR), 2))) * GraRad 
        + calibracionCabeceo;
      //Con este if hacemos que la primera señal del balanceo sea la del acelerometro y el resto 
      //provengan del resultado del filtro. Se consigue un proceso algo mas rapido.
      if (i == 0) {
        balanceoG = balanceoA + (gz / GaG) * dt / 1000; 
        cabeceoG  = cabeceoA  + (gy / GaG) * dt / 1000;
        i++;
      }
      //angulo=anguloAnterior+ (velocidadAngular/131.072)*dt  dt corresponde con el delay
      else {
        balanceoG = balanceo + (gz / GaG) * dt / 1000; //gz*sensibilidad. GaR (de giroscopo a Grados)[GaR=1
        cabeceoG  = cabeceo  + (gy / GaG) * dt / 1000; //sensibilidad] es la inversa de la sensibilidad
      }
      balanceo  = (ganancia * balanceoG + (1 - ganancia) * balanceoA);
      cabeceo   = (ganancia * cabeceoG  + (1 - ganancia) * cabeceoA);
      delay(dt);

      //-------------------------------------------------------------------------------------------------
      // Estabilizacion   -------------------------------------------------------------------------------
      //-------------------------------------------------------------------------------------------------
      /*
         Cambia la posición de la cabeza 1 de cada 10 veces que se toma la posicion
         La toma de datos va mucho mas rapido que la respuesta de los servos. Estos tienen una
         velocidad de 6º/10ms pero un arranque lento, si cambiaran de posicion cada 5 ms, se
         produciria un cabeceo indeseado.
         Cada 10 veces se estabiliza bien.
      */
      if (n % 10 == 0) {
        // ------------- Gestion del balanceo  ------------------
        if (balanceo < -margenError) {
          giroAlfa1--;
          giroAlfa2--;
        }
        else if (balanceo > margenError) {
          giroAlfa1++;
          giroAlfa2++;
        }
        else {
          contadorParaPasarBalanceo++;
        }
        // ------------- Gestion del cabeceo  ------------------
        if (cabeceo > margenError) {
          giroDelta1--;
          giroDelta2--;
        }
        else if (cabeceo < -margenError) {
          giroDelta1++;
          giroDelta2++;
        }
        else {
          contadorParaPasarCabeceo++;
        }

        IrA(giroAlfa1, giroAlfa2, ang2, ang3, ang4, ang5, giroDelta1, giroDelta2);
      }
    }
    ledOff();

    // Deja pasar la ejecucion cuando se alcanza el minimo requerido en los contadores
  } while (contadorParaPasarBalanceo < necesariosParaPasar 
    and contadorParaPasarCabeceo < necesariosParaPasar);

  //----------------------------------------------------------------------------------------------------
  // inicioAlfa e inicioDelta se usaran en la siguiente funcion.
  // El 0.5 es para redondear. Sin el 0.5 simplemente se truncan los decimales (6.9->6)
  // pero con +0.5 se redondea => 6.9+0.5=7.4->7.
  //----------------------------------------------------------------------------------------------------
  inicioA1 = giroAlfa1 + 0.5;
  inicioA2 = giroAlfa2 + 0.5;
  inicioD1 = giroDelta1 + 0.5;
  inicioD2 = giroDelta2 + 0.5;
}
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

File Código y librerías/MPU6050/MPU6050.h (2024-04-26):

// I2Cdev library collection - MPU6050 I2C device class
// Based on InvenSense MPU-6050 register map document rev. 2.0, 5/19/2011 (RM-MPU-6000A-00)
// 10/3/2011 by Jeff Rowberg <jeff@rowberg.net>
// Updates should (hopefully) always be available at https://github.com/jrowberg/i2cdevlib
//
// Changelog:
//     ... - ongoing debug release

// NOTE: THIS IS ONLY A PARIAL RELEASE. THIS DEVICE CLASS IS CURRENTLY UNDERGOING ACTIVE
// DEVELOPMENT AND IS STILL MISSING SOME IMPORTANT FEATURES. PLEASE KEEP THIS IN MIND IF
// YOU DECIDE TO USE THIS PARTICULAR CODE FOR ANYTHING.

/* ============================================
I2Cdev device library code is placed under the MIT license
Copyright (c) 2012 Jeff Rowberg
Permission is hereby granted, free of charge, to any person obtaining a copy
of this software and associated documentation files (the "Software"), to deal
in the Software without restriction, including without limitation the rights
to use, copy, modify, merge, publish, distribute, sublicense, and/or sell
copies of the Software, and to permit persons to whom the Software is
furnished to do so, subject to the following conditions:
The above copyright notice and this permission notice shall be included in
all copies or substantial portions of the Software.
THE SOFTWARE IS PROVIDED "AS IS", WITHOUT WARRANTY OF ANY KIND, EXPRESS OR
IMPLIED, INCLUDING BUT NOT LIMITED TO THE WARRANTIES OF MERCHANTABILITY,
FITNESS FOR A PARTICULAR PURPOSE AND NONINFRINGEMENT. IN NO EVENT SHALL THE
AUTHORS OR COPYRIGHT HOLDERS BE LIABLE FOR ANY CLAIM, DAMAGES OR OTHER
LIABILITY, WHETHER IN AN ACTION OF CONTRACT, TORT OR OTHERWISE, ARISING FROM,
OUT OF OR IN CONNECTION WITH THE SOFTWARE OR THE USE OR OTHER DEALINGS IN
THE SOFTWARE.
===============================================
*/

#ifndef _MPU6050_H_
#define _MPU6050_H_

#include "I2Cdev.h"

// supporting link:  http://forum.arduino.cc/index.php?&topic=143444.msg1079517#msg1079517
// also: http://forum.arduino.cc/index.php?&topic=141571.msg1062899#msg1062899s

#ifdef __AVR__
#include <avr/pgmspace.h>
#else
//#define PROGMEM /* empty */
//#define pgm_read_byte(x) (*(x))
//#define pgm_read_word(x) (*(x))
//#define pgm_read_float(x) (*(x))
//#define PSTR(STR) STR
#endif


#define MPU6050_ADDRESS_AD0_LOW     0x68 // address pin low (GND), default for InvenSense evaluation board
#define MPU6050_ADDRESS_AD0_HIGH    0x69 // address pin high (VCC)
#define MPU6050_DEFAULT_ADDRESS     MPU6050_ADDRESS_AD0_LOW

#define MPU6050_RA_XG_OFFS_TC       0x00 //[7] PWR_MODE, [6:1] XG_OFFS_TC, [0] OTP_BNK_VLD
#define MPU6050_RA_YG_OFFS_TC       0x01 //[7] PWR_MODE, [6:1] YG_OFFS_TC, [0] OTP_BNK_VLD
#define MPU6050_RA_ZG_OFFS_TC       0x02 //[7] PWR_MODE, [6:1] ZG_OFFS_TC, [0] OTP_BNK_VLD
#define MPU6050_RA_X_FINE_GAIN      0x03 //[7:0] X_FINE_GAIN
#define MPU6050_RA_Y_FINE_GAIN      0x04 //[7:0] Y_FINE_GAIN
#define MPU6050_RA_Z_FINE_GAIN      0x05 //[7:0] Z_FINE_GAIN
#define MPU6050_RA_XA_OFFS_H        0x06 //[15:0] XA_OFFS
#define MPU6050_RA_XA_OFFS_L_TC     0x07
#define MPU6050_RA_YA_OFFS_H        0x08 //[15:0] YA_OFFS
#define MPU6050_RA_YA_OFFS_L_TC     0x09
#define MPU6050_RA_ZA_OFFS_H        0x0A //[15:0] ZA_OFFS
#define MPU6050_RA_ZA_OFFS_L_TC     0x0B
#define MPU6050_RA_SELF_TEST_X      0x0D //[7:5] XA_TEST[4-2], [4:0] XG_TEST[4-0]
#define MPU6050_RA_SELF_TEST_Y      0x0E //[7:5] YA_TEST[4-2], [4:0] YG_TEST[4-0]
#define MPU6050_RA_SELF_TEST_Z      0x0F //[7:5] ZA_TEST[4-2], [4:0] ZG_TEST[4-0]
#define MPU6050_RA_SELF_TEST_A      0x10 //[5:4] XA_TEST[1-0], [3:2] YA_TEST[1-0], [1:0] ZA_TEST[1-0]
#define MPU6050_RA_XG_OFFS_USRH     0x13 //[15:0] XG_OFFS_USR
#define MPU6050_RA_XG_OFFS_USRL     0x14
#define MPU6050_RA_YG_OFFS_USRH     0x15 //[15:0] YG_OFFS_USR
#define MPU6050_RA_YG_OFFS_USRL     0x16
#define MPU6050_RA_ZG_OFFS_USRH     0x17 //[15:0] ZG_OFFS_USR
#define MPU6050_RA_ZG_OFFS_USRL     0x18
#define MPU6050_RA_SMPLRT_DIV       0x19
#define MPU6050_RA_CONFIG           0x1A
#define MPU6050_RA_GYRO_CONFIG      0x1B
#define MPU6050_RA_ACCEL_CONFIG     0x1C
#define MPU6050_RA_FF_THR           0x1D
#define MPU6050_RA_FF_DUR           0x1E
#define MPU6050_RA_MOT_THR          0x1F
#define MPU6050_RA_MOT_DUR          0x20
#define MPU6050_RA_ZRMOT_THR        0x21
#define MPU6050_RA_ZRMOT_DUR        0x22
#define MPU6050_RA_FIFO_EN          0x23
#define MPU6050_RA_I2C_MST_CTRL     0x24
#define MPU6050_RA_I2C_SLV0_ADDR    0x25
#define MPU6050_RA_I2C_SLV0_REG     0x26
#define MPU6050_RA_I2C_SLV0_CTRL    0x27
#define MPU6050_RA_I2C_SLV1_ADDR    0x28
#define MPU6050_RA_I2C_SLV1_REG     0x29
#define MPU6050_RA_I2C_SLV1_CTRL    0x2A
#define MPU6050_RA_I2C_SLV2_ADDR    0x2B
#define MPU6050_RA_I2C_SLV2_REG     0x2C
#define MPU6050_RA_I2C_SLV2_CTRL    0x2D
#define MPU6050_RA_I2C_SLV3_ADDR    0x2E
#define MPU6050_RA_I2C_SLV3_REG     0x2F
#define MPU6050_RA_I2C_SLV3_CTRL    0x30
#define MPU6050_RA_I2C_SLV4_ADDR    0x31
#define MPU6050_RA_I2C_SLV4_REG     0x32
#define MPU6050_RA_I2C_SLV4_DO      0x33
#define MPU6050_RA_I2C_SLV4_CTRL    0x34
#define MPU6050_RA_I2C_SLV4_DI      0x35
#define MPU6050_RA_I2C_MST_STATUS   0x36
#define MPU6050_RA_INT_PIN_CFG      0x37
#define MPU6050_RA_INT_ENABLE       0x38
#define MPU6050_RA_DMP_INT_STATUS   0x39
#define MPU6050_RA_INT_STATUS       0x3A
#define MPU6050_RA_ACCEL_XOUT_H     0x3B
#define MPU6050_RA_ACCEL_XOUT_L     0x3C
#define MPU6050_RA_ACCEL_YOUT_H     0x3D
#define MPU6050_RA_ACCEL_YOUT_L     0x3E
#define MPU6050_RA_ACCEL_ZOUT_H     0x3F
#define MPU6050_RA_ACCEL_ZOUT_L     0x40
#define MPU6050_RA_TEMP_OUT_H       0x41
#define MPU6050_RA_TEMP_OUT_L       0x42
#define MPU6050_RA_GYRO_XOUT_H      0x43
#define MPU6050_RA_GYRO_XOUT_L      0x44
#define MPU6050_RA_GYRO_YOUT_H      0x45
#define MPU6050_RA_GYRO_YOUT_L      0x46
#define MPU6050_RA_GYRO_ZOUT_H      0x47
#define MPU6050_RA_GYRO_ZOUT_L      0x48
#define MPU6050_RA_EXT_SENS_DATA_00 0x49
#define MPU6050_RA_EXT_SENS_DATA_01 0x4A
#define MPU6050_RA_EXT_SENS_DATA_02 0x4B
#define MPU6050_RA_EXT_SENS_DATA_03 0x4C
#define MPU6050_RA_EXT_SENS_DATA_04 0x4D
#define MPU6050_RA_EXT_SENS_DATA_05 0x4E
#define MPU6050_RA_EXT_SENS_DATA_06 0x4F
#define MPU6050_RA_EXT_SENS_DATA_07 0x50
#define MPU6050_RA_EXT_SENS_DATA_08 0x51
#define MPU6050_RA_EXT_SENS_DATA_09 0x52
#define MPU6050_RA_EXT_SENS_DATA_10 0x53
#define MPU6050_RA_EXT_SENS_DATA_11 0x54
#define MPU6050_RA_EXT_SENS_DATA_12 0x55
#define MPU6050_RA_EXT_SENS_DATA_13 0x56
#define MPU6050_RA_EXT_SENS_DATA_14 0x57
#define MPU6050_RA_EXT_SENS_DATA_15 0x58
#define MPU6050_RA_EXT_SENS_DATA_16 0x59
#define MPU6050_RA_EXT_SENS_DATA_17 0x5A
#define MPU6050_RA_EXT_SENS_DATA_18 0x5B
#define MPU6050_RA_EXT_SENS_DATA_19 0x5C
#define MPU6050_RA_EXT_SENS_DATA_20 0x5D
#define MPU6050_RA_EXT_SENS_DATA_21 0x5E
#define MPU6050_RA_EXT_SENS_DATA_22 0x5F
#define MPU6050_RA_EXT_SENS_DATA_23 0x60
#define MPU6050_RA_MOT_DETECT_STATUS    0x61
#define MPU6050_RA_I2C_SLV0_DO      0x63
#define MPU6050_RA_I2C_SLV1_DO      0x64
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
